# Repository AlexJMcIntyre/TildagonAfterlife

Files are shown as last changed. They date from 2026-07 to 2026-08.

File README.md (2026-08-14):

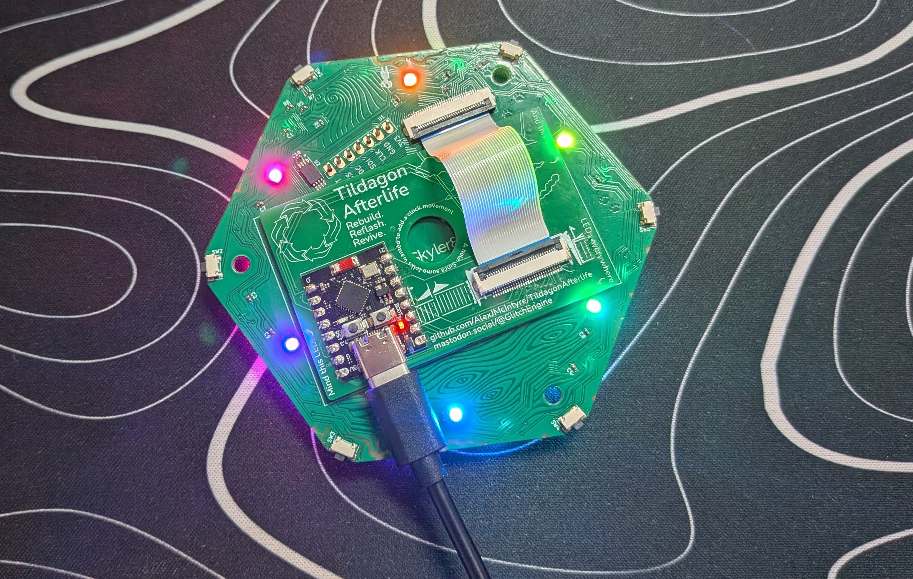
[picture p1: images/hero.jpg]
Breadboard prototype


## **Tildagon Afterlife Board**

Bring your old EMF 2024 Tildagon front board back to life.

The **Tildagon Afterlife Board** is a minimal driver board for the original EMF 2024 Tildagon front PCB. It connects to the badge using the existing 30-pin FFC connector and is driven by an **ESP32-C3 SuperMini module**, turning the retired front board into a standalone development platform.

When the **Spaceagon** upgrade arrived in 2026, the original front board was replaced with new hardware. It felt like too nice a piece of engineering to end up in a drawer or a bin, so this project was born.

The goal is simple: provide an inexpensive board that lets the original hardware live on. Flash WLED if you just want pretty lights, write your own firmware in MicroPython, Arduino, ESP-IDF, or anything else you fancy, or use it as the basis for your own experiments.

## Features
- Drives all 18 addressable RGB LEDs
  - 12 LEDs on the front
  - 6 LEDs on the rear
- Supports all 6 corner buttons
- Breaks out the LCD connector
  - The original display moved to the 2026 badge, but replacement displays are inexpensive and can be fitted later.
- Preserves the original EEPROM
  - The EEPROM is intentionally not connected. There weren't enough spare GPIOs on the ESP32-C3, I couldn't think of a compelling use case, and leaving it untouched means the original badge contents remain intact should you ever want to rebuild it.

## Required Parts
To build one you'll need:
- ESP32-C3 SuperMini
- JUSHUO AFC01-S30FCC-00 30-pin FFC connector (or equivalent)
- 30-pin, 0.5 mm pitch FFC cable, same-side (Type A)

The connector spacing works out to around 40 mm, although the shortest cable I was able to source was 50 mm, which works perfectly well.

Totally optionally, you can buy a new screen. Search for GC9A01 1.28" round LCD modules.

## Project Status
**Current status: Live! You can buy this!**
Check out [my Ko-fi shop](https://ko-fi.com/s/6f3e26f617) to get both bare and pre-assembled PCBs

You can follow the project's progress on Mastodon:
https://mastodon.social/@GlitchEngine

## Planned Software
Demo scripts are on the way to show how to use each of the board's features. Don't expect a polished software ecosystem, but I'll publish anything useful I write along the way. If you build something cool, I'd love to hear about it.

## License
Firmware and documentation are licensed under the MIT Licence. Hardware design files are licensed under CERN-OHL-P v2.
Tildagon is a project by the EMF Camp team. This project is an independent community accessory and is not affiliated with or endorsed by EMF Camp.

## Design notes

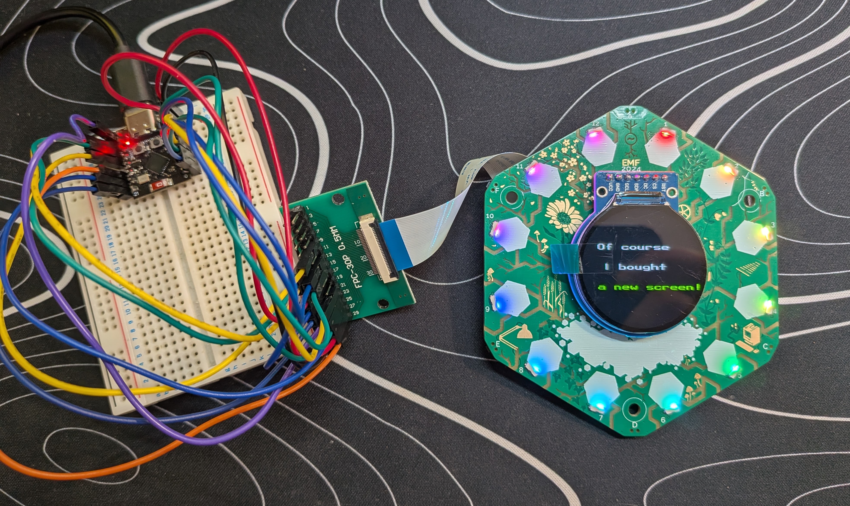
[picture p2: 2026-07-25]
images/breadboard.jpg

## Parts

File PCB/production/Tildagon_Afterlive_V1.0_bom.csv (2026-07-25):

Designator | Footprint | Quantity | Value | LCSC Part #
ESP32-C3_SUPERMINI | MODULE_ESP32-C3_SUPERMINI | 1 | ESP32-C3_SUPERMINI
J1 | Jushuo_AFC01-S30FCC-00_1x30-1MP_P0.50mm_Horizontal | 1 | AFC01-S30FCC-00

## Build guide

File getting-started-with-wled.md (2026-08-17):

# Getting Started with WLED on Tildagon Afterlife

Looking for some oven-ready software to make flashy lights happen on Tildagon Afterlife? WLED is a great beginner-friendly option that is super quick to set up.

## What is WLED?

[WLED](https://kno.wled.ge/) is open-source ESP32 firmware that controls addressable LEDs (like WS2812/NeoPixel) over Wi-Fi. It has over 100 snazzy effects built in and is packed with neat features including nightlight auto dimming, presets and a clock mode. Effects can be controlled through a web interface, from an app or even via MQTT or Home Assistant.

## Install WLED via the web installer

1. Connect the ESP32-C3 SuperMini board to your computer using a data-capable USB-C cable.
2. Open [install.wled.me](https://install.wled.me) in a Chromium-based browser.
3. Choose the correct serial port for your device. If you don't see it in the list you might need to hold down the BOOT button whilst tapping RESET to make it show up.
4. Select the latest WLED build and flash it.
5. Enter your Wi-Fi SSID and password to connect WLED to your Wi-Fi network.
6. Click `Visit Device` to open the web interface.

If WLED cannot connect to your Wi-Fi network, it starts a Wi-Fi access point that you can join from your phone.

## Install the phone app (optional)

If you'd rather control WLED through the app, you can install it via your phone's app store. It should automatically detect a fresh WLED instance, as long as both devices are connected to the same Wi-Fi network.

- [View on Apple App Store](https://apps.apple.com/gb/app/wled-official-app/id6446207239)
- [View on Google Play Store](https://play.google.com/store/apps/details?id=ca.cgagnier.wlednativeandroid)

## First-time LED setup

After first boot, you'll need to let WLED know what pin the LEDs are connected to and how many we have. Head to `Config -> LED & Hardware` and set length to `18` and Data GPIO to `10`.

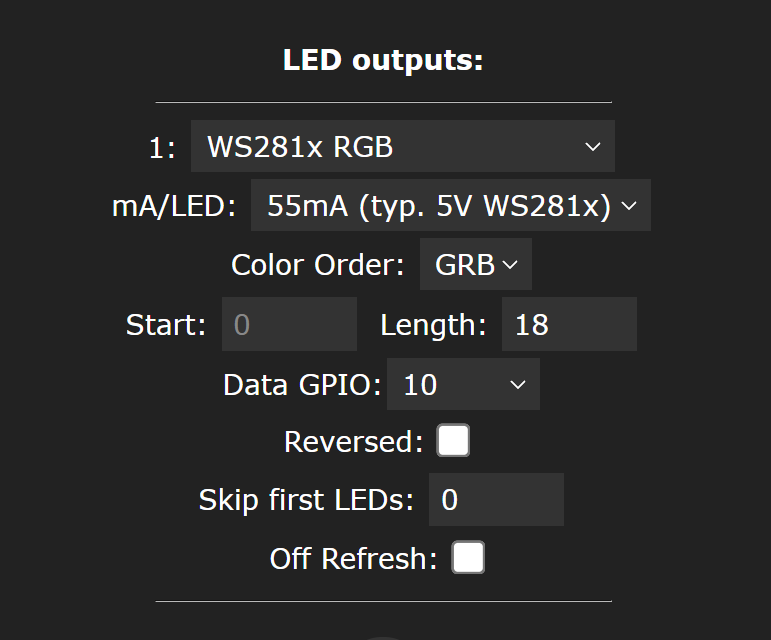
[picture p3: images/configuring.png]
Configuring the LEDs


## Effects and presets

1. Choose an effect/colour you like in the main UI (note that most effects will need you to select both an effect and a colour).
2. Once you've tuned your effect to your satisfaction, save it as a preset using the `+ Preset` button so you can use it again later.

## Segments

If you set up the front and back LEDs as separate segments, you can run different effects or colours on the front and back. Click `+ Add segment` on the web UI (or the segments button at the bottom of the app) to get started.

- Segment 0 (Front): LEDs 0-12
- Segment 1 (Back): LEDs 12-18

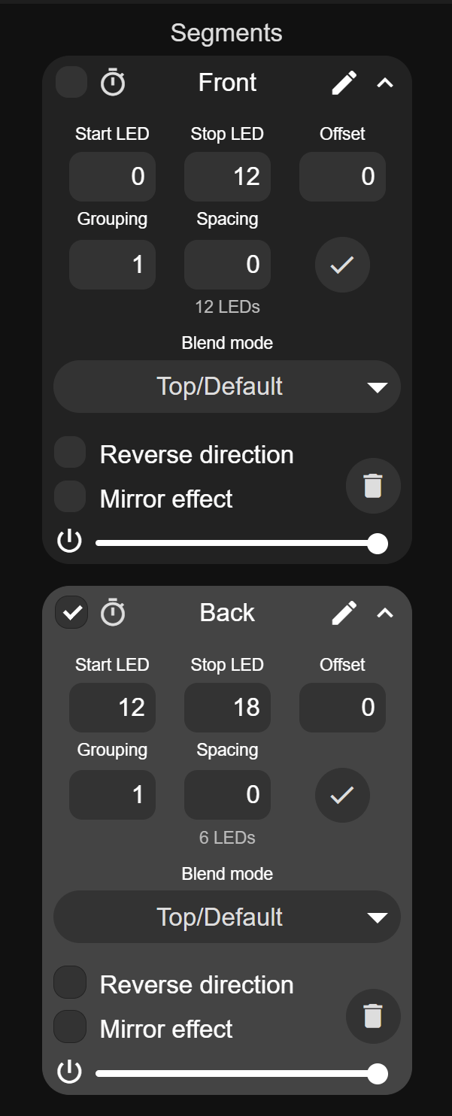
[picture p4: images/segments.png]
Setting up the segments


## Buttons

The Tildagon front plate is blessed with six buttons. To use them with WLED, head to `Config -> LED & Hardware -> Hardware Setup`.

Under `Buttons` add the Tildagon button GPIOs as `pushbutton`:

- Button 0/A (GPIO4)
- Button 1/B (GPIO5)
- Button 2/C (GPIO20)
- Button 3/D (GPIO21)
- Button 4/E (GPIO2)
- Button 5/F (GPIO0)

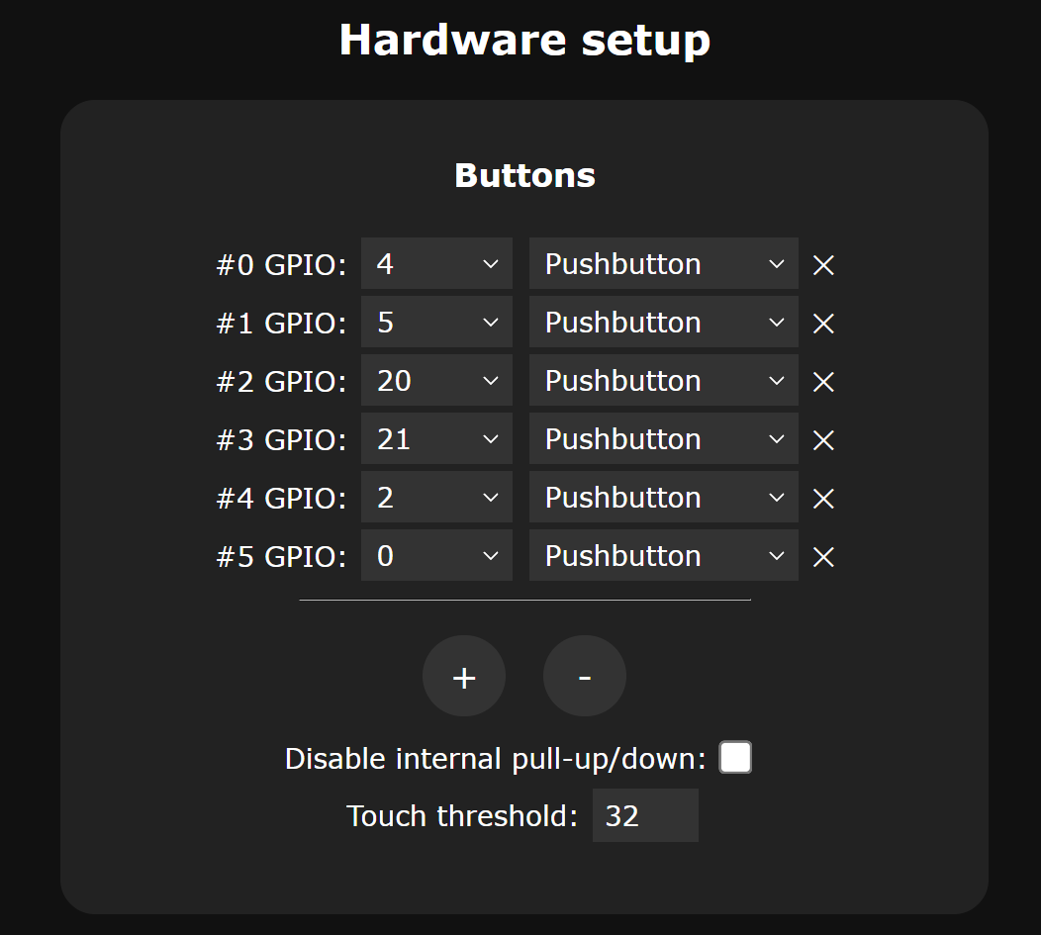
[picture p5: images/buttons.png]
Configuring the buttons


GPIO0 (F) is assigned as Button 0 by default, so you may need to unassign it, reboot WLED, and then add it back in the right place to get all the buttons mapped correctly. The `Reboot` option lives under the `Info` tab.

In `Config -> Time & Macros -> Button Action Presets`, you can assign short, long and double button pushes to your presets to recall your saved effects. `Default Action (0)` toggles the LEDs on and off, so you probably want to leave at least one button assigned to that.

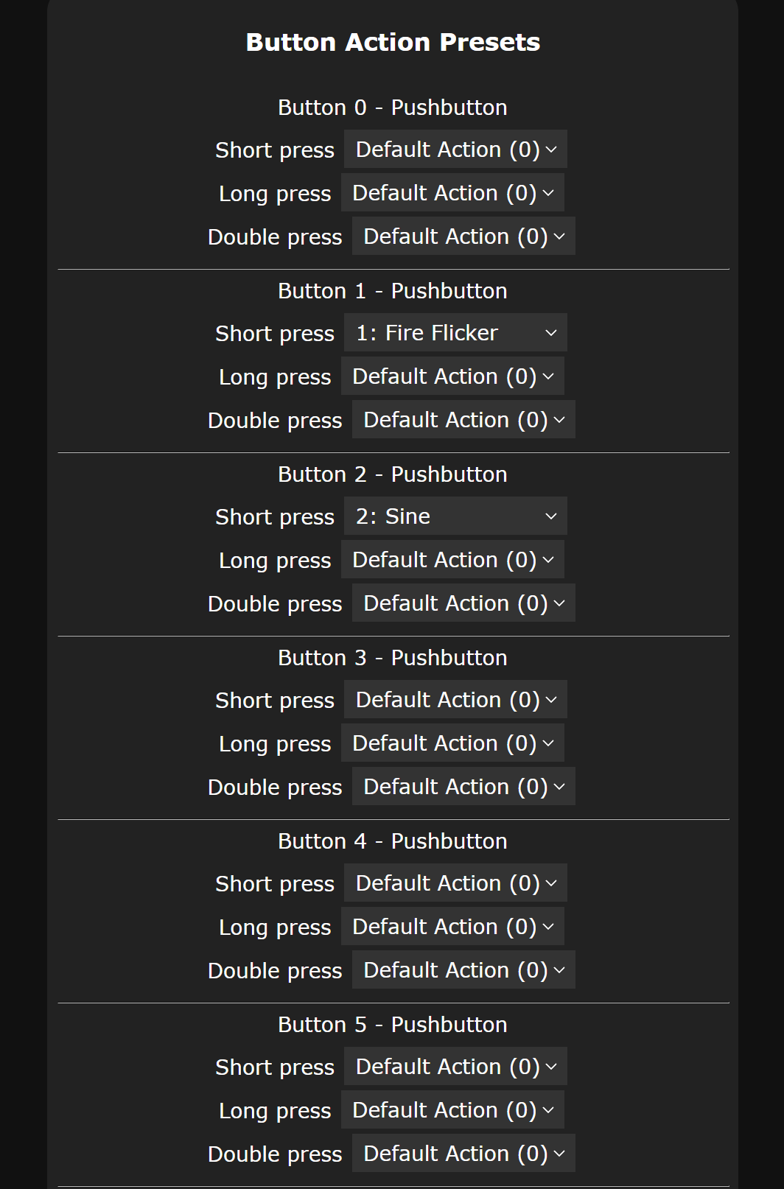
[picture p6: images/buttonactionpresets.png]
Assigning Button Action Presets


Note that GPIO2 (E) and GPIO0 (F) are boot-related pins on ESP32-C3. Avoid holding those buttons while powering up or resetting.

## Clock mode

A neat thing you can do with this board is to use the 12 front LEDs as a clock face. In `Config -> Time & Macros`:

1. Enable NTP time sync and set your timezone correctly.

2. Enable Analog Clock Overlay

3. Select LEDs 0-11.

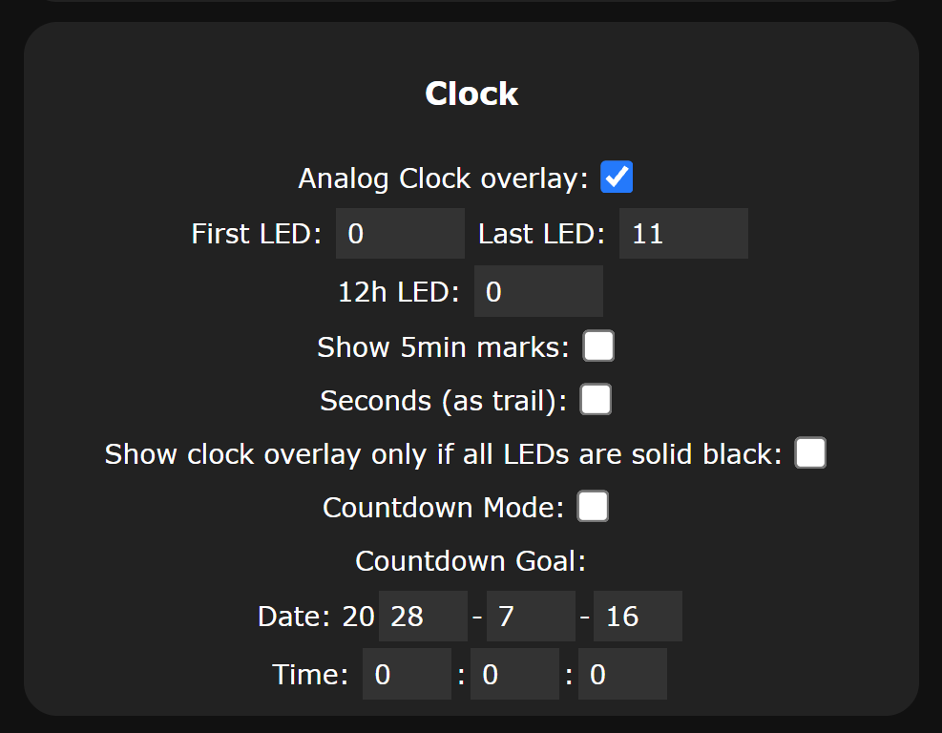
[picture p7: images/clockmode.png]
Clock mode settings


Clock mode is an overlay, so will work on top of other effects (or you can select 'Show clock overlay only if all LEDs are solid black'). There's also a countdown mode if you want to countdown until EMF 2028 :)

Note that you will need to apply a slight physical offset to the board to make the clock LEDs line up with a standard clock face!

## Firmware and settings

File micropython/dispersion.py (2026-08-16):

import machine
import neopixel
import time

# One white point splits into a spectrum of colours.
# Slight differences in particle speed cause the spectrum
# to drift and interfere, and it looks like chaos at first but
# if you keep watching, patterns and nodes start reforming out
# of the noise. 

# settings

LED_PIN = 10
NUM_LEDS = 18
FRONT_LEDS = 12

PARTICLES = 12

# How quickly the spectrum moves.
BASE_SPEED = 0.005

# How much the particles differ in speed.
SPEED_SPREAD = 1 / 2400

# How far each particle illuminates neighbouring LEDs.
PARTICLE_SPREAD = 0.75

# Frame delay. Lower = faster / smoother.
FRAME_DELAY = 0.01

# Maximum brightness of each colour component.
COLOUR_LEVEL = 85



# hardware

leds = neopixel.NeoPixel(
    machine.Pin(LED_PIN),
    NUM_LEDS
)



# Spectrum

# The colours are evenly distributed around the RGB colour
# wheel. Because they all start in the same place, they begin
# as white and gradually separate into a spectrum.

SPECTRUM = [
    [COLOUR_LEVEL,  0,              0],
    [COLOUR_LEVEL,  COLOUR_LEVEL//2, 0],
    [COLOUR_LEVEL,  COLOUR_LEVEL,   0],
    [COLOUR_LEVEL//2, COLOUR_LEVEL, 0],
    [0,              COLOUR_LEVEL,  0],
    [0,              COLOUR_LEVEL,  COLOUR_LEVEL//2],
    [0,              COLOUR_LEVEL,  COLOUR_LEVEL],
    [0,              COLOUR_LEVEL//2, COLOUR_LEVEL],
    [0,              0,              COLOUR_LEVEL],
    [COLOUR_LEVEL//2, 0,             COLOUR_LEVEL],
    [COLOUR_LEVEL,   0,              COLOUR_LEVEL],
    [COLOUR_LEVEL,   0,              COLOUR_LEVEL//2],
]



# particle


class Particle:

    def __init__(self, position, colour, speed, spread):
        self.position = position
        self.colour = colour
        self.speed = speed
        self.spread = spread


# Create the spectrum

particles = []

for i in range(PARTICLES):

    speed = BASE_SPEED + i * SPEED_SPREAD

    particles.append(
        Particle(
            position=0,
            colour=SPECTRUM[i],
            speed=speed,
            spread=PARTICLE_SPREAD
        )
    )



# Main loop

while True:

    # Draw the particles onto the LEDs

    for led in range(FRONT_LEDS):

        red = 0
        green = 0
        blue = 0

        for particle in particles:

            # Distance around the circular LED arrangement
            distance = abs(particle.position - led)
            distance = min(
                distance,
                FRONT_LEDS - distance
            )

            # Does this particle illuminate this LED?
            if distance <= particle.spread:

                brightness = (
                    1.0 -
                    distance / particle.spread
                )

                red += particle.colour[0] * brightness
                green += particle.colour[1] * brightness
                blue += particle.colour[2] * brightness



        # Normalise the colour if it is brighter than the LEDs can display.
        # This preserves the colour balance rather than simply clipping individual RGB channels.


        maximum = max(red, green, blue)

        if maximum > 255:

            scale = 255 / maximum

            red *= scale
            green *= scale
            blue *= scale


        leds[led] = (
            int(red),
            int(green),
            int(blue)
        )



    # Move the spectrum

    for particle in particles:

        particle.position += particle.speed

        # Wrap around the circular display
        particle.position %= FRONT_LEDS


    # Update the LEDs

    leds.write()

    time.sleep(FRAME_DELAY)

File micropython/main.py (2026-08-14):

#Simple rainbow demo script

import machine
import neopixel
import time

LED_PIN = 10
NUM_LEDS = 18

leds = neopixel.NeoPixel(
    machine.Pin(LED_PIN),
    NUM_LEDS
)


def wheel(position):
    """Convert 0-255 colour wheel position to RGB."""

    position %= 256

    if position < 85:
        return (
            position * 3,
            255 - position * 3,
            0
        )

    if position < 170:
        position -= 85
        return (
            255 - position * 3,
            0,
            position * 3
        )

    position -= 170

    return (
        0,
        position * 3,
        255 - position * 3
    )


# Position of every physical LED around the dial.
#
# Front:
#   0, 1, 2, 3, 4, 5, 6, 7, 8, 9, 10, 11
#
# Back:
#   1.5, 3.5, 5.5, 7.5, 9.5, 11.5

led_positions = []

for i in range(12):
    led_positions.append(i)

for i in range(6):
    led_positions.append(i * 2 + 1.5)


offset = 0

while True:

    for led in range(NUM_LEDS):

        position = led_positions[led]

        leds[led] = wheel(
            int(position * 256 / 12) + offset
        )

    leds.write()

    offset = (offset + 1) % 256

    time.sleep(0.02)

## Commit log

2026-07-25 Add README for Tildagon Afterlife Board project
    Added detailed project description, features, required parts, project status, planned software, and license information for the Tildagon Afterlife Board.
2026-07-25 Update FFC cable description in README
